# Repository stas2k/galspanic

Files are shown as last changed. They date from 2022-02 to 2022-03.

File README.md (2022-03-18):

# GALSPanic - X68000 SRAM Expansion

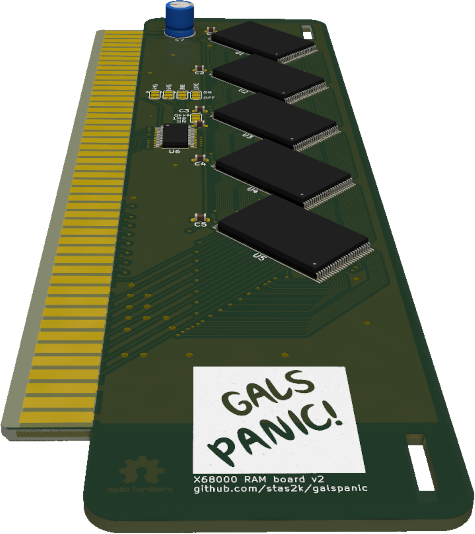
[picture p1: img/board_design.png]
Board design


This repo contains Kicad sources for a Static RAM expansion board for Sharp X68000 personal computer.
Please use latest git version of kicad to open the project, or version >6.0 once it gets released.

## Design
The expansion is implemented using 2MB static RAM chips to make the design simpler.
Address decoder is implemented using a ATF22V10 GAL chip. Source code for it is available in `gal/` directory.

Board dimensions are taken from the [midiori](https://github.com/tdaede/midiori) project.

The board can support up to 10MB of memory and assumes you already have 2MB built in.

A fourth address line is routed and the board can support 1MB systems by masking half of the first memory chip. However, the GAL equations are not written for this case. Let me know if you have such a system.

## Compatibility
Following systems have been reported to work:
- Super
- Expert
- ACE
- XVI
- Pro
- 68030

## GAL Equations

You can compile `.pld` GAL equations using [GALasm](https://github.com/daveho/GALasm).

## Board production

I use JLCPCB with the following options:
* PCB Thickness: 1.6
* Surface Finish: ENIG-RoHS
* Gold Fingers: Yes
* 45°finger chamfered: Yes

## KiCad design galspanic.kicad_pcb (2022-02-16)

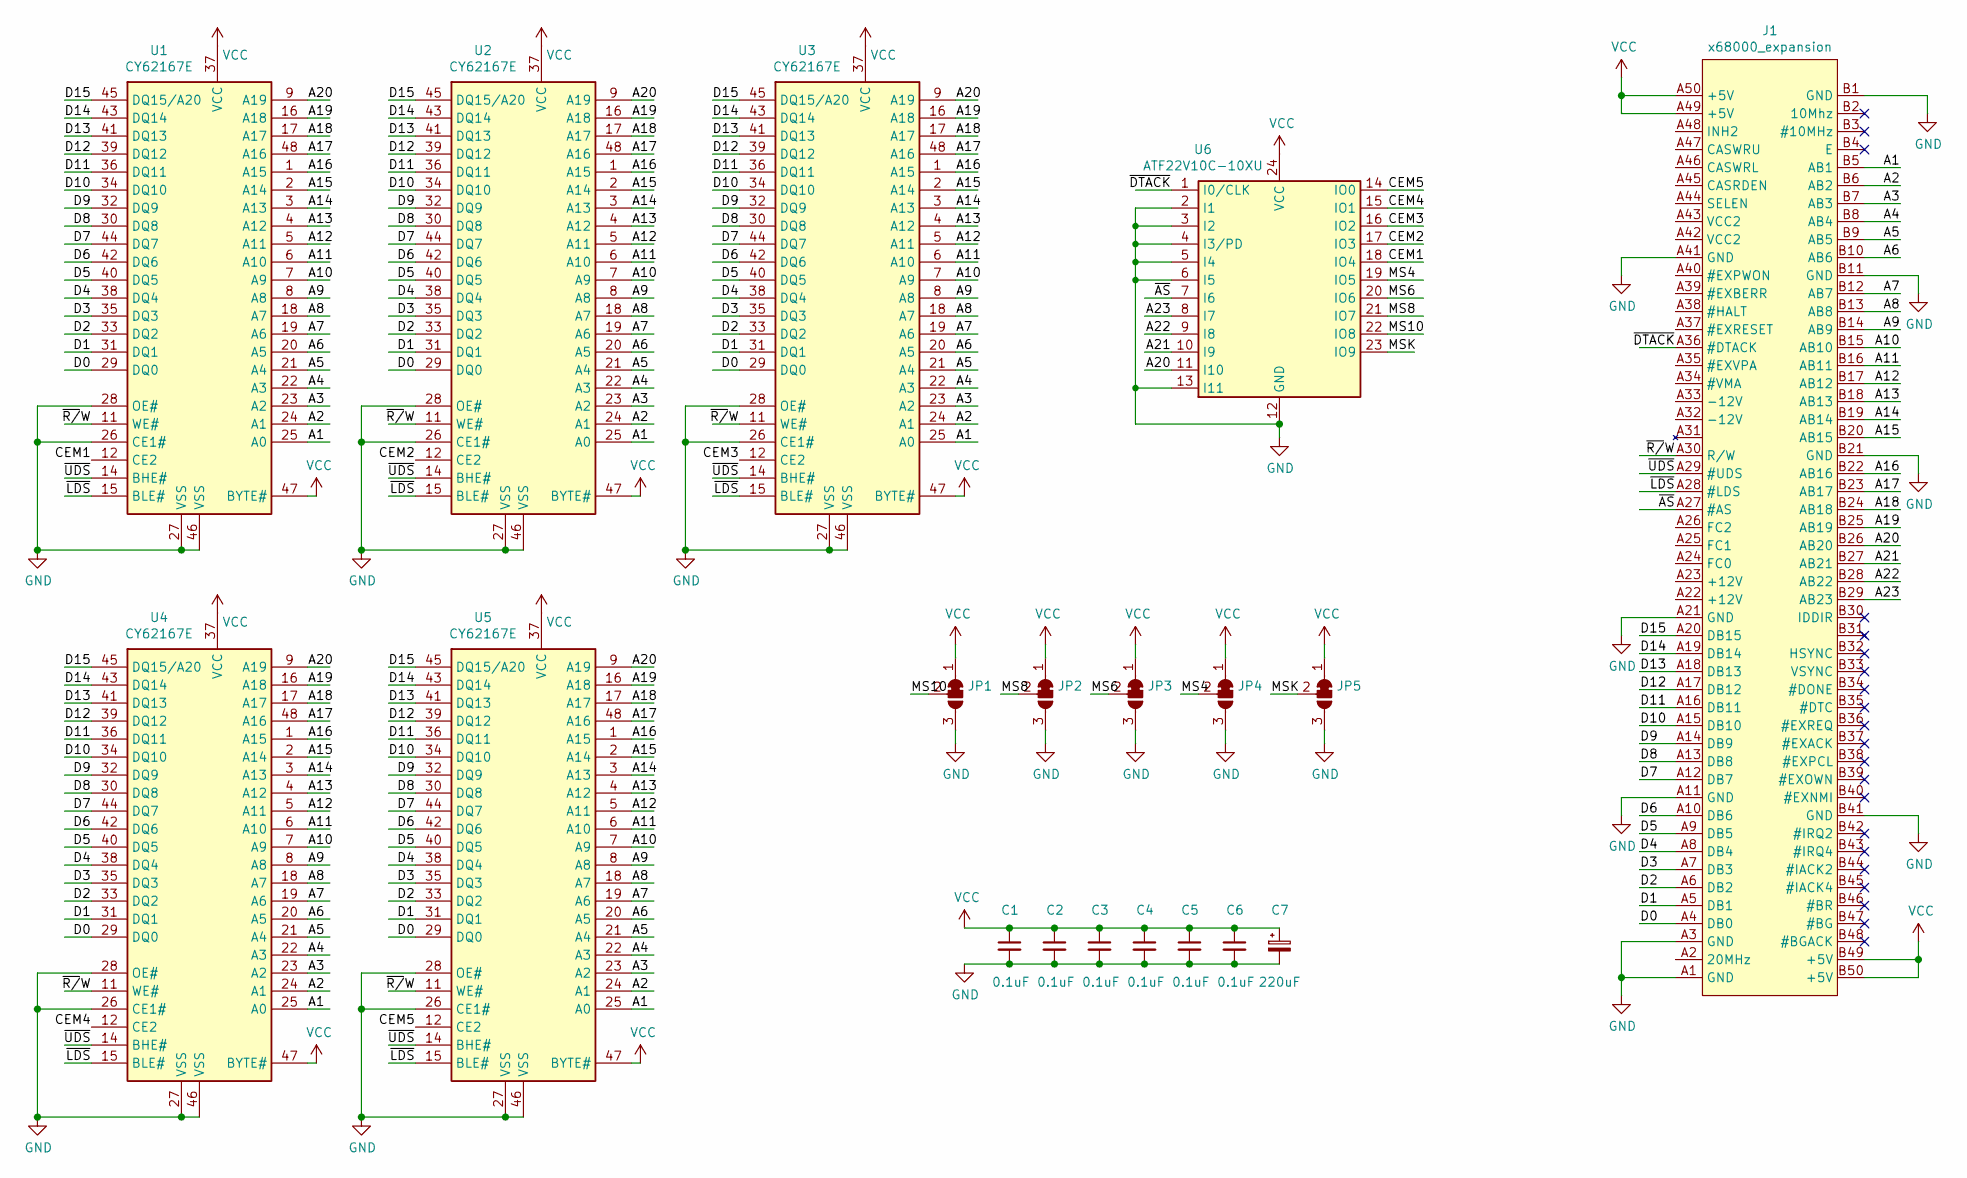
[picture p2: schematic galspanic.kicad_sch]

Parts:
C1, C2, C3, C4, C5, C6: 0.1uF; C_0603_1608Metric_Pad1.08x0.95mm_HandSolder
C7: 220uF; CP_Radial_D6.3mm_P2.50mm
J1: x68000_expansion
JP1, JP2, JP3, JP4, JP5: SolderJumper_3_Bridged12; SolderJumper-3_P1.3mm_Bridged12_RoundedPad1.0x1.5mm
U1, U2, U3, U4, U5: CY62167E; TSOP-I-48_18.4x12mm_P0.5mm
U6: ATF22V10C-10XU; TSSOP-24_4.4x7.8mm_P0.65mm

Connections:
/A1: J1.B5 (AB1), U1.25 (A0), U2.25 (A0), U3.25 (A0), U4.25 (A0), U5.25 (A0)
/A2: J1.B6 (AB2), U1.24 (A1), U2.24 (A1), U3.24 (A1), U4.24 (A1), U5.24 (A1)
/A3: J1.B7 (AB3), U1.23 (A2), U2.23 (A2), U3.23 (A2), U4.23 (A2), U5.23 (A2)
/A4: J1.B8 (AB4), U1.22 (A3), U2.22 (A3), U3.22 (A3), U4.22 (A3), U5.22 (A3)
/A5: J1.B9 (AB5), U1.21 (A4), U2.21 (A4), U3.21 (A4), U4.21 (A4), U5.21 (A4)
/A6: J1.B10 (AB6), U1.20 (A5), U2.20 (A5), U3.20 (A5), U4.20 (A5), U5.20 (A5)
/A7: J1.B12 (AB7), U1.19 (A6), U2.19 (A6), U3.19 (A6), U4.19 (A6), U5.19 (A6)
/A8: J1.B13 (AB8), U1.18 (A7), U2.18 (A7), U3.18 (A7), U4.18 (A7), U5.18 (A7)
/A9: J1.B14 (AB9), U1.8 (A8), U2.8 (A8), U3.8 (A8), U4.8 (A8), U5.8 (A8)
/A10: J1.B15 (AB10), U1.7 (A9), U2.7 (A9), U3.7 (A9), U4.7 (A9), U5.7 (A9)
/A11: J1.B16 (AB11), U1.6 (A10), U2.6 (A10), U3.6 (A10), U4.6 (A10), U5.6 (A10)
/A12: J1.B17 (AB12), U1.5 (A11), U2.5 (A11), U3.5 (A11), U4.5 (A11), U5.5 (A11)
/A13: J1.B18 (AB13), U1.4 (A12), U2.4 (A12), U3.4 (A12), U4.4 (A12), U5.4 (A12)
/A14: J1.B19 (AB14), U1.3 (A13), U2.3 (A13), U3.3 (A13), U4.3 (A13), U5.3 (A13)
/A15: J1.B20 (AB15), U1.2 (A14), U2.2 (A14), U3.2 (A14), U4.2 (A14), U5.2 (A14)
/A16: J1.B22 (AB16), U1.1 (A15), U2.1 (A15), U3.1 (A15), U4.1 (A15), U5.1 (A15)
/A17: J1.B23 (AB17), U1.48 (A16), U2.48 (A16), U3.48 (A16), U4.48 (A16), U5.48 (A16)
/A18: J1.B24 (AB18), U1.17 (A17), U2.17 (A17), U3.17 (A17), U4.17 (A17), U5.17 (A17)
/A19: J1.B25 (AB19), U1.16 (A18), U2.16 (A18), U3.16 (A18), U4.16 (A18), U5.16 (A18)
/A20: J1.B26 (AB20), U1.9 (A19), U2.9 (A19), U3.9 (A19), U4.9 (A19), U5.9 (A19), U6.11 (I10)
/A21: J1.B27 (AB21), U6.10 (I9)
/A22: J1.B28 (AB22), U6.9 (I8)
/A23: J1.B29 (AB23), U6.8 (I7)
/CEM1: U1.12 (CE2), U6.18 (IO4)
/CEM2: U2.12 (CE2), U6.17 (IO3)
/CEM3: U3.12 (CE2), U6.16 (IO2)
/CEM4: U4.12 (CE2), U6.15 (IO1)
/CEM5: U5.12 (CE2), U6.14 (IO0)
/D0: J1.A4 (DB0), U1.29 (DQ0), U2.29 (DQ0), U3.29 (DQ0), U4.29 (DQ0), U5.29 (DQ0)
/D1: J1.A5 (DB1), U1.31 (DQ1), U2.31 (DQ1), U3.31 (DQ1), U4.31 (DQ1), U5.31 (DQ1)
/D2: J1.A6 (DB2), U1.33 (DQ2), U2.33 (DQ2), U3.33 (DQ2), U4.33 (DQ2), U5.33 (DQ2)
/D3: J1.A7 (DB3), U1.35 (DQ3), U2.35 (DQ3), U3.35 (DQ3), U4.35 (DQ3), U5.35 (DQ3)
/D4: J1.A8 (DB4), U1.38 (DQ4), U2.38 (DQ4), U3.38 (DQ4), U4.38 (DQ4), U5.38 (DQ4)
/D5: J1.A9 (DB5), U1.40 (DQ5), U2.40 (DQ5), U3.40 (DQ5), U4.40 (DQ5), U5.40 (DQ5)
/D6: J1.A10 (DB6), U1.42 (DQ6), U2.42 (DQ6), U3.42 (DQ6), U4.42 (DQ6), U5.42 (DQ6)
/D7: J1.A12 (DB7), U1.44 (DQ7), U2.44 (DQ7), U3.44 (DQ7), U4.44 (DQ7), U5.44 (DQ7)
/D8: J1.A13 (DB8), U1.30 (DQ8), U2.30 (DQ8), U3.30 (DQ8), U4.30 (DQ8), U5.30 (DQ8)
/D9: J1.A14 (DB9), U1.32 (DQ9), U2.32 (DQ9), U3.32 (DQ9), U4.32 (DQ9), U5.32 (DQ9)
/D10: J1.A15 (DB10), U1.34 (DQ10), U2.34 (DQ10), U3.34 (DQ10), U4.34 (DQ10), U5.34 (DQ10)
/D11: J1.A16 (DB11), U1.36 (DQ11), U2.36 (DQ11), U3.36 (DQ11), U4.36 (DQ11), U5.36 (DQ11)
/D12: J1.A17 (DB12), U1.39 (DQ12), U2.39 (DQ12), U3.39 (DQ12), U4.39 (DQ12), U5.39 (DQ12)
/D13: J1.A18 (DB13), U1.41 (DQ13), U2.41 (DQ13), U3.41 (DQ13), U4.41 (DQ13), U5.41 (DQ13)
/D14: J1.A19 (DB14), U1.43 (DQ14), U2.43 (DQ14), U3.43 (DQ14), U4.43 (DQ14), U5.43 (DQ14)
/D15: J1.A20 (DB15), U1.45 (DQ15/A20), U2.45 (DQ15/A20), U3.45 (DQ15/A20), U4.45 (DQ15/A20), U5.45 (DQ15/A20)
/MS4: JP4.2 (C), U6.19 (IO5)
/MS6: JP3.2 (C), U6.20 (IO6)
/MS8: JP2.2 (C), U6.21 (IO7)
/MS10: JP1.2 (C), U6.22 (IO8)
/MSK: JP5.2 (C), U6.23 (IO9)
/~AS: J1.A27 (#AS), U6.7 (I6)
/~DTACK: J1.A36 (#DTACK), U6.1 (I0/CLK)
/~LDS: J1.A28 (#LDS), U1.15 (BLE#), U2.15 (BLE#), U3.15 (BLE#), U4.15 (BLE#), U5.15 (BLE#)
/~R/W: J1.A30 (R/W), U1.11 (WE#), U2.11 (WE#), U3.11 (WE#), U4.11 (WE#), U5.11 (WE#)
/~UDS: J1.A29 (#UDS), U1.14 (BHE#), U2.14 (BHE#), U3.14 (BHE#), U4.14 (BHE#), U5.14 (BHE#)
GND: C1.2, C2.2, C3.2, C4.2, C5.2, C6.2, C7.2, J1.A1 (GND), J1.A3 (GND), J1.A11 (GND), J1.A21 (GND), J1.A41 (GND), J1.B1 (GND), J1.B11 (GND), J1.B21 (GND), J1.B41 (GND), JP1.3 (B), JP2.3 (B), JP3.3 (B), JP4.3 (B), JP5.3 (B), U1.26 (CE1#), U1.27 (VSS), U1.28 (OE#), U1.46 (VSS), U2.26 (CE1#), U2.27 (VSS), U2.28 (OE#), U2.46 (VSS), U3.26 (CE1#), U3.27 (VSS), U3.28 (OE#), U3.46 (VSS), U4.26 (CE1#), U4.27 (VSS), U4.28 (OE#), U4.46 (VSS), U5.26 (CE1#), U5.27 (VSS), U5.28 (OE#), U5.46 (VSS), U6.2 (I1), U6.3 (I2), U6.4 (I3/PD), U6.5 (I4), U6.6 (I5), U6.12 (GND), U6.13 (I11)
VCC: C1.1, C2.1, C3.1, C4.1, C5.1, C6.1, C7.1, J1.A49 (+5V), J1.A50 (+5V), J1.B49 (+5V), J1.B50 (+5V), JP1.1 (A), JP2.1 (A), JP3.1 (A), JP4.1 (A), JP5.1 (A), U1.37 (VCC), U1.47 (BYTE#), U2.37 (VCC), U2.47 (BYTE#), U3.37 (VCC), U3.47 (BYTE#), U4.37 (VCC), U4.47 (BYTE#), U5.37 (VCC), U5.47 (BYTE#), U6.24 (VCC)

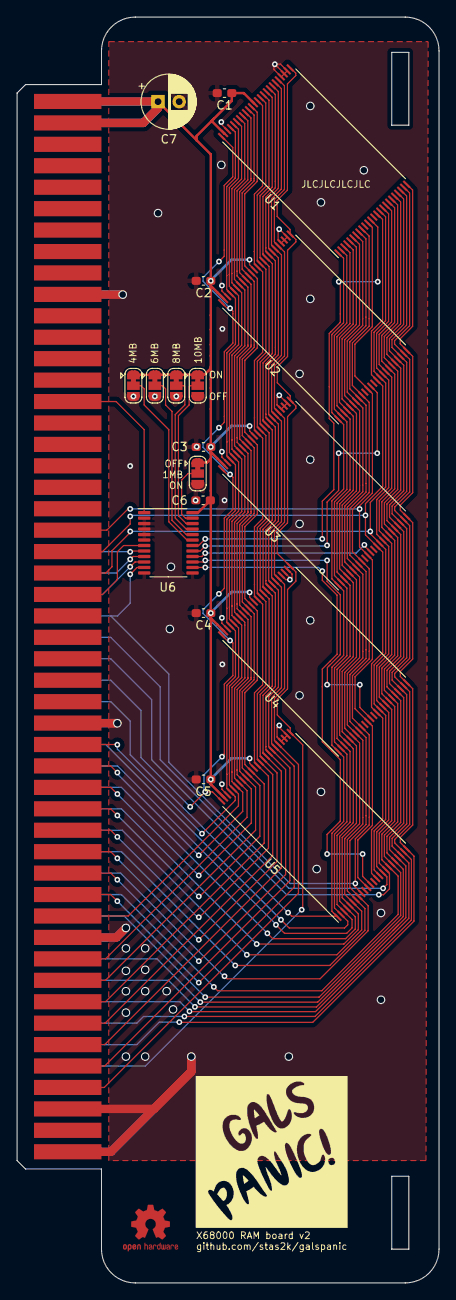
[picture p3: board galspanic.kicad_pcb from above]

Board: 2 copper layers, 50.0 x 150.0 mm, 19 parts (0 on the bottom side), 56 nets.

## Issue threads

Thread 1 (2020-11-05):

Unable to open the pcb with kicad

pascalorama, 2020-11-05:
Hello there,

thanks for this project , i wanted to check the pcb , but i'm unable to open it with KiCad for windows,
Tried the latest version stable 5.1.7 , nightly build and a older version from May 2020. Do you have a link to the version you're using ?

thanks in advance and best regards

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

stas2k, 2020-11-23:
You will have to use the dev version of kicad to open these. I do not know if ready made builds are available for Windows.

stas2k, 2020-11-26:
I am going to close the issue as you can solve it by using a newer version

Closed 2020-11-26.

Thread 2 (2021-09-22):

Can you add a BOM

peon374, 2021-09-22:
If you can add a BOM to the release files I can make it without having to work out what version of kicad makes those file extensions.

stas2k, 2022-02-16:
Merge request with BOM is welcome.

Closed 2022-02-16.

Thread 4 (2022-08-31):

Jumper configuration for a 10Mb Pro System

rapiqui, 2022-08-31:
Hi,

I have made a couple of these expansions, as the project is very promising.
Unfortunately the first tests did not recognize the memory expansion.
The setup is as follows:

- Gals Panic! Expansion board fitted with 5*2Mb SRAM
- 1Mb RAM masking off
- 4,6,8 and 10 Mb switches on "ON" position
- Standard .jed equations (the one published, which I compiled)
- X68000 Pro with 2Mb internal Expansion

Once the X68000 boots, i execute switch.x and configured 10240 Kb, save the settings and reboot.
Once rebooted I get a message if I want to switch back to 2Mb.

I tried SSF2 and it does not even startup, so it seems that for some reason the memory expansion is not detected.

Am I missing anything?

Thank you.

rapiqui, 2022-09-05:
Hi,

Just an update on this. I wrongly used 22V10CQZ-20XU GALs instead of the atf22v10c-10xu, which are faster.

I would suggest to include a BOM, as both memory modules and the GAL are very specific for this project.

Regards

stas2k, 2022-09-11:
Hello, @rapiqui! I ran into the same issue it seems. Will keep this thread updated and BOM once I understand the issue a bit more. It should not matter that GAL is faster, if the pinout is the the same(which it seems it is).

rapiqui, 2022-09-11:
Thank you. I have changed the issue title based on the fact that this might not be related to the GAL model.

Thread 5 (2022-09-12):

DTACK Issue

plowcat, 2022-09-12:
On the schematic DTACK is Pin 1 on the GAL where as in the PLD file its is Pin 23. Since it is an output it can't be on Pin 1.

I noticed this after assembling a board with 3 SRAM chips and testing in an ACE with a Sharp 1 MB expansion on the internal memory expansion header. I worked around the issue by cutting the link on the "1 MB" jumper and adding a wire between the middle pad of the jumper and Pin 1 of the GAL. I tested with a program found somewhere called "mtest.r" which passed.

I also felt that the GAL was getting warm from driving DTACK as push-pull rather than open drain so I added an open drain buffer. It is maybe less warm, but I don't have a way to measure well. It worked with and without the buffer so this may not be an issue. I think using the tri-state outputs on the GAL should be able get the same effect.

rapiqui, 2022-11-04:
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

Hi,

I assume then there might be an error on the current GAL routing and that fix you applied would be required if using 4 SRAM chips?
As I mentioned on another issue I had no success with my built unit and I was blaming the GAL speed, but perhaps the problem is caused by this.

Thanks

ArcadeKing, 2023-10-02:
Thanks for posting this fix.
Looking at the PLD via WinCUPL Pin 1 (DTACK) isn't fused to anything internally anyway so tying it to MSK or NDTACK as its called in the PLD shouldn't do any damage.
GAL's tend to run hot normally. I've had my Galspanic installed for 2 days and the GAL is warm to the touch.

tdaede, 2023-10-22:
Driving DTACK push-pull is likely to prevent other expansion cards from working that are installed alongside the RAM expansion. (It seems that this is currently accidentally being avoided by the DTACK line not being driven at all).

badass-boss, 2024-08-05:
Any updates on this issue? What is the final solution for this then? Anyone cares to update the design?

badass-boss, 2024-08-08:
I guess the original creator is no longer interested ¯\_(ツ)_/¯ Shame

Also has anyone fully reverse engineered this design:
http://retropc.net/gimons/marsx/index.html

It uses a low power 8MB SRAM (AS6C6416 I think) with voltage translators which should be way more affordable if you want to go up by 8MB right away and this seems to make much more sense. What I want to change here is convert it to a standard removable card just like the card here in question

stas2k, 2024-08-08:
>     1. the full kicad project so we could edit (I'd make larger "finger holes" to make it easier to pull the board from the slot)

Send changes as MR and I will merge.

>
>     2. I'd love to see the GAL being able to start the memory at 1MB rather than 2MB, which would be great for owners of the CZ-600, Ace and Pro machines not having to pay LOADS of money for the 1MB card required to expand the X68000 before using any slot-based RAM card.

This is also possible with a GAL bitstream change, but even easier is to design a separate RAM board to go into that specialized slot. It already provides all the right control signals to drive a DRAM chip. You just need to find one which can handle the 5V. If it has more RAM than needed, just ground the unused pins.

I have implemented the required changes to make the board behave correctly on DTACK, just need to spin some and test it out. Basically it needs a pinout change and a bitstream change.

stas2k, 2024-08-08:
> I guess the original creator is no longer interested ¯_(ツ)_/¯ Shame

I got what I wanted out of the project - learned 68000 interfacing, got started in programmable logic, and expanded RAM in my X68000. If someone is still fresh and willing to help, MRs are welcome.

I will fix the current issue, and do a production run of the boards, as I still have some spare SRAM chips left.

badass-boss, 2024-08-09:
> @badass-boss not sure if you seen a modern board like Edu Arana's Etarikashikoshi, which is an 8MB + MIDI all in one card, it has only a single RAM chip, and an Altera FPGA, so it might be even easier to make, but the code is of course, proprietary.
>
> MarsX is a great idea as it doesn't use a slot, but it's not easily removable...

Yes but since this is github I'm interested in building one, not buying one

I'm more interested in reverse engineering that Marsx 8MB RAM card and as far as I can tell it should be easy to do because it is just a 8MB SRAM 3V chip so the signals need to be translated between 3V and 5V and then connected to X68000, that's it. Also what is the purpose of those PLD chips on both of these cards? Are they supposed to configure memory starting address? But why, I thought all expansion RAM cards are supposed to start from $200000?? In this instance there is no need to implement any programmable chip on board at all and it can be reduced to just 74 chips, all it needs is a NOR gate and XOR gate which can reduce costs even further and there is no need to go through the hassle of programming anything

Anyway good to hear there will be some official updates over here

stas2k, 2024-08-09:
> In this instance there is no need to implement any programmable chip on board at all and it can be reduced to just 74 chips,

You can do it with this SRAM-based setup, but not with the other, older boards. They all used DRAM, and require quite a bit of logic to refresh and multiplex data/address buses.

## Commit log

2020-09-10 first upload
    [galspanic.kicad_pcb, galspanic.kicad_sch]
2020-09-12 route A20, fix power cap footprint
    [galspanic.kicad_pcb, galspanic.kicad_sch]
2020-09-25 gal: add 4MB board
2020-09-25 pcb: add grounding around A20
    [galspanic.kicad_pcb]
2020-09-25 readme: update board image
2020-12-10 update board image
2020-12-27 upgrade kicad
2021-01-28 gal: add 6MB board
2021-01-28 pcb: add memory size jumpers
    [galspanic.kicad_pcb, galspanic.kicad_sch]
2021-01-28 pcb: v1.2 release
    [galspanic.kicad_pcb]
2021-10-15 release a smaller board with no buffers
    [galspanic.kicad_pcb, galspanic.kicad_sch]
